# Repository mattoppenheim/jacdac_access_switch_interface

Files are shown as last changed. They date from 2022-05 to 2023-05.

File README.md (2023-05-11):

Accessibility switch interface module for the Microsoft Jacdac project https://microsoft.github.io/jacdac-docs/.

The boards tested as working.

The board has two channels for interfacing accessibility switches or devices that can be controlled by an accessibility switch.

Each channel has a 3.5mm jack socket which can be configured either as an input or an output. This means that a switch can be connected to the board and used to operate Jacdac hardware, or that the module can act as a switch to control external devices or switchable software.

Each channel uses an opto-isolated relay to enable the board to pass enough current so that e.g. switchable toys can be operated.

To use the board as an output to control external hardware or software, use a double ended 3.5mm cable plugged into the 3.5mm socket.

Schematics and PCB layout are made using KiCad Version: 6.99.0-unknown-2887+gf4fa3b02c5+deb11, release build, running on Debian.

The board layout conforms with Ec30Template20x20 80-1.0 drawing.PDF. The Jacdac edge connector conforms with drawing JacdacEdgeConnectorRef 101-1.1 drawing.PDF.

Matthew Oppenheim 2023
matt@mattoppenheim.com

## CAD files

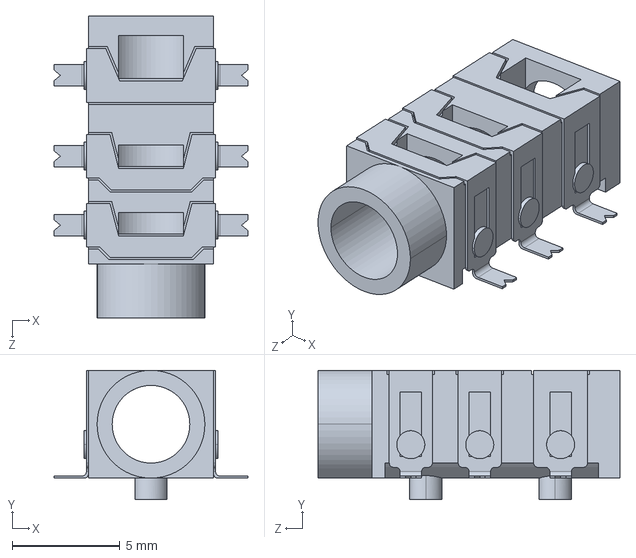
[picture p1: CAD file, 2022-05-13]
3dshapes/JackPJ313D.STEP
9.00 x 6.00 x 14.0 mm

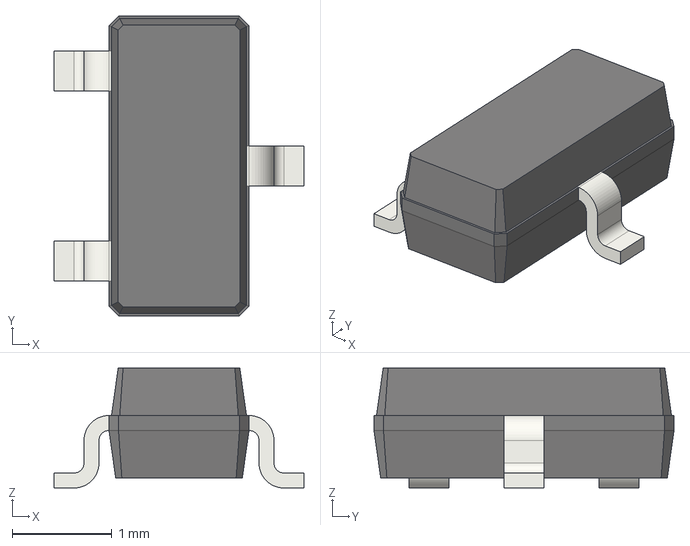
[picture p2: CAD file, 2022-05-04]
3dshapes/SOT-23.step
2.50 x 3.00 x 1.20 mm

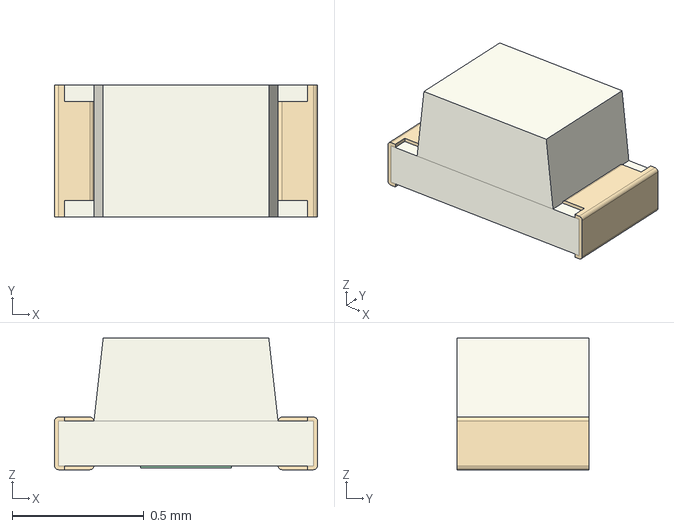
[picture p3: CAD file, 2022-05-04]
3dshapes/LED_0402_1005Metric.step
1.00 x 0.5 x 0.5 mm

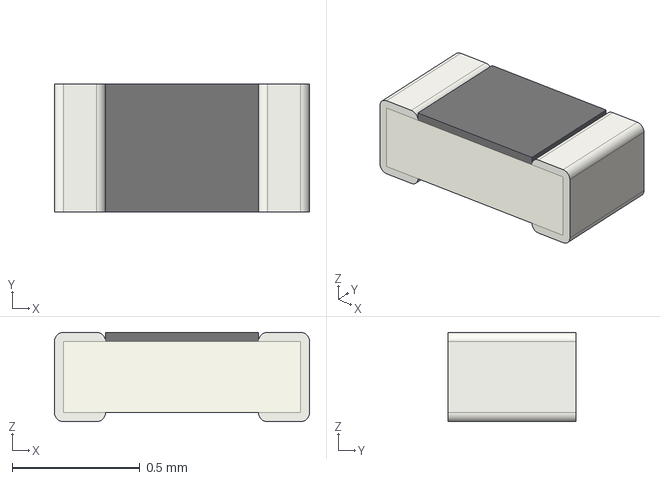
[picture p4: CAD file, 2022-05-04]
3dshapes/R_0402_1005Metric.step
1.00 x 0.5 x 0.35 mm

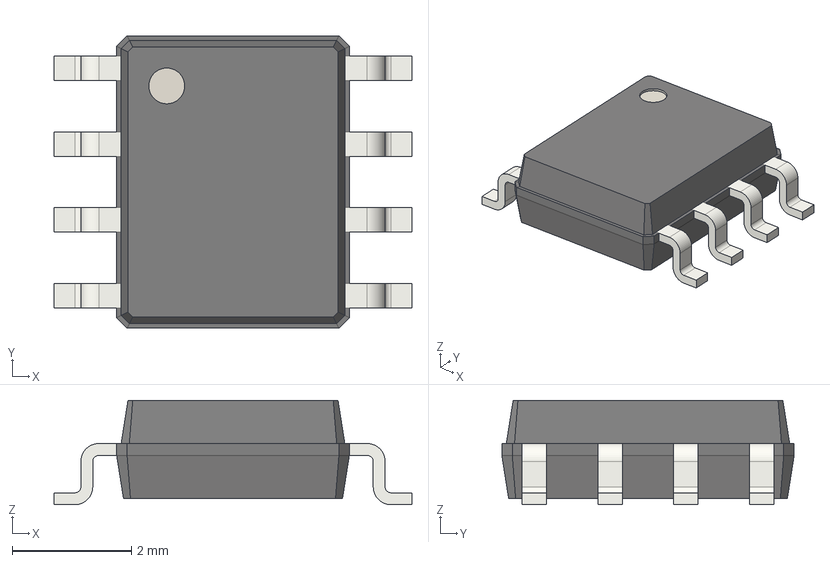
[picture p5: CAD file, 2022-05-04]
3dshapes/SOIC-8_W3.9mm.step
6.00 x 4.90 x 1.75 mm

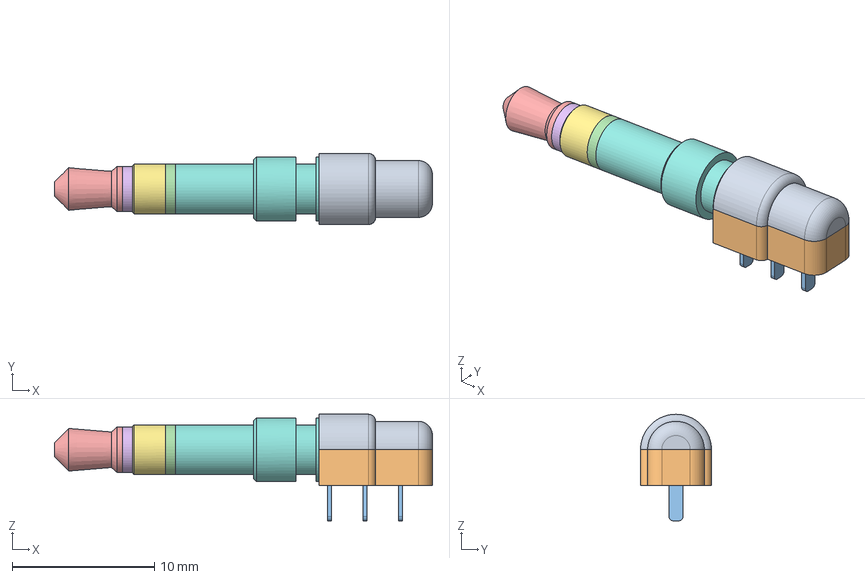
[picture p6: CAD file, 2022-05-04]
3dshapes/Tensility_-_54-00036.step
26.6 x 5.00 x 7.50 mm

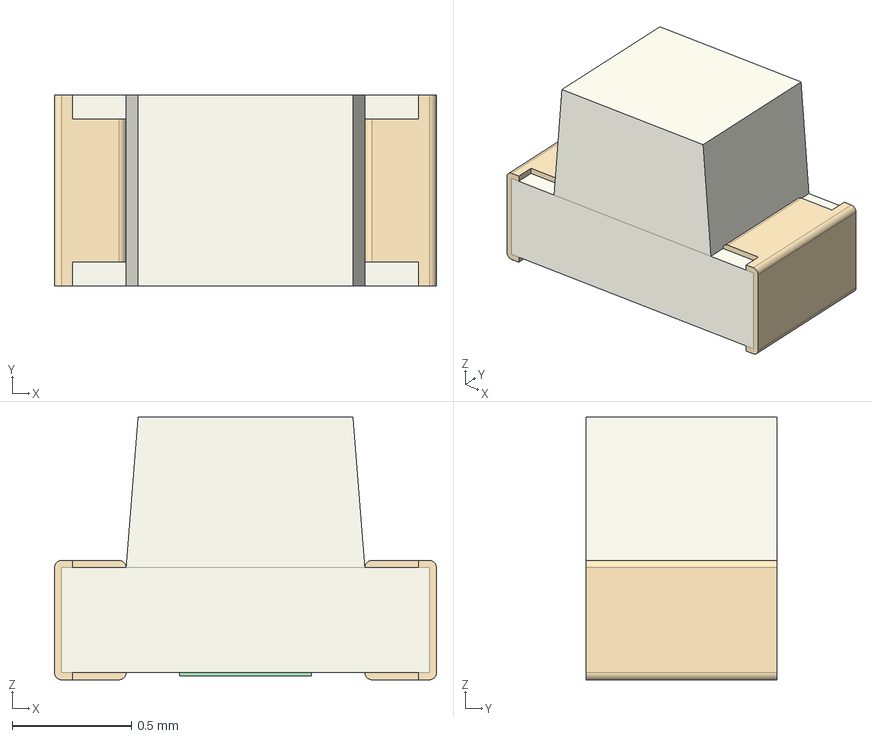
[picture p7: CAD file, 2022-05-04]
3dshapes/LED_0603_1608Metric.step
1.60 x 0.8 x 1.10 mm

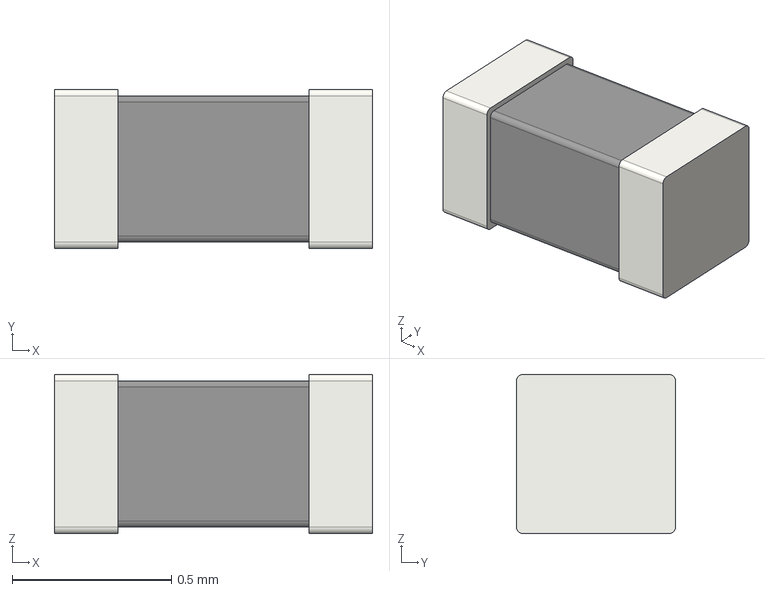
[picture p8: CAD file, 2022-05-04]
3dshapes/L_0402_1005Metric.step
1.00 x 0.5 x 0.5 mm

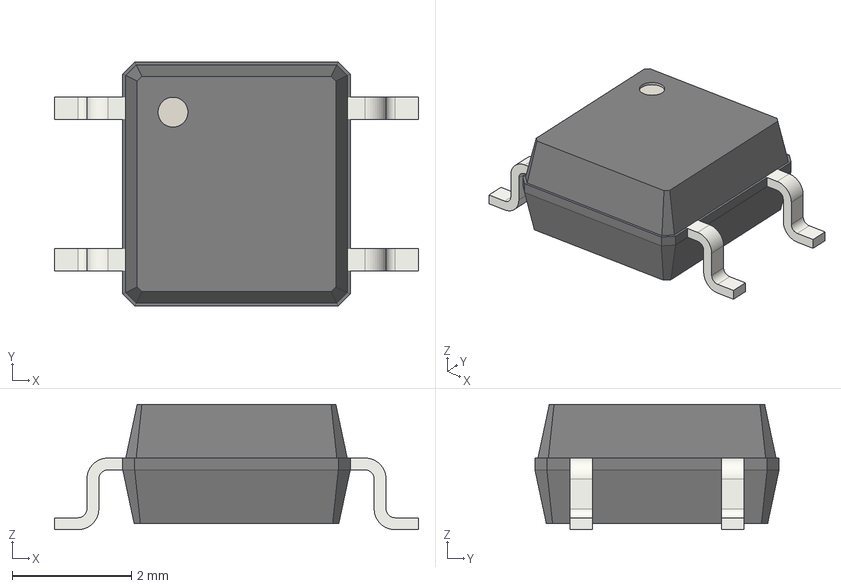
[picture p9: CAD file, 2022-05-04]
3dshapes/SOP-4_3.8x4.1mm_P2.54mm.step
6.10 x 4.09 x 2.10 mm

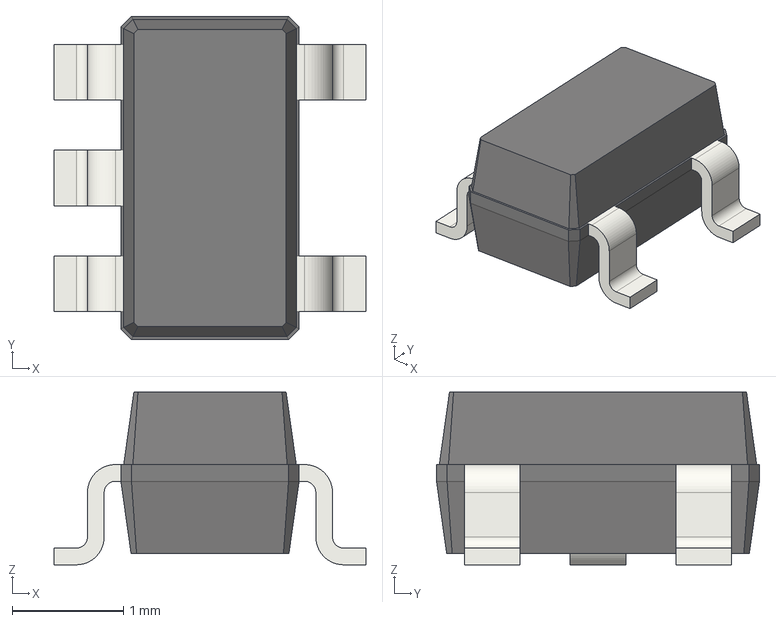
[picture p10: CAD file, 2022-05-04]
3dshapes/SOT-23-5.step
2.80 x 2.90 x 1.55 mm

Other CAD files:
3dshapes/LED_0603_1608Metric_Castellated.step
3dshapes/C_0402_1005Metric.step

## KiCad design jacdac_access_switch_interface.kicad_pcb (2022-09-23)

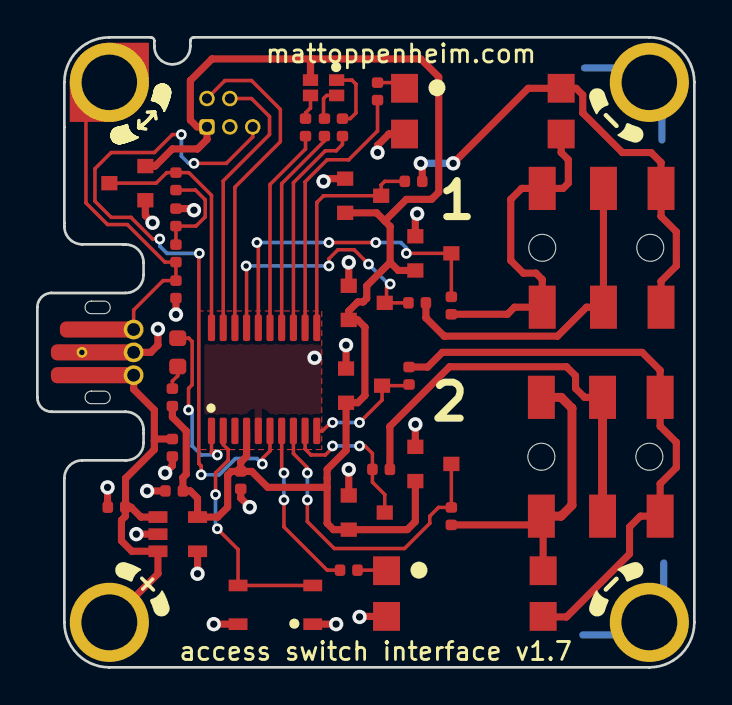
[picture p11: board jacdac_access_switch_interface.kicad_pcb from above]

Board: 2 copper layers, 36.5 x 35.0 mm, 42 parts (0 on the bottom side), 34 nets.

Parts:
C1: 1uF, 10V; C_0402_1005Metric
C2: 1uF; C_0402_1005Metric
C3: 33pF; C_0402_1005Metric
C4: 0.1uF; C_0402_1005Metric
D1: RCLAMP0521P-N; D_0402_1005Metric
D2: RCLAMP0521-P; D_0402_1005Metric
D3, D4, D6, D7, D8, D9, D10: BAT54S; SOT-23
D5: LTST-C19HE1WT; LED_LTST-C19HE1WT
D12: LED_status; LED_0603_1608Metric
FB1: 1kOhm @ 100MHz; L_0402_1005Metric
J1: Conn_Jacdac_CardEdge; JD-PEC-02_Prerouted_recessed
J2: Conn_HackConnect; HackConnect_P1.27mm
J3, J4: jack_3.5_pj313d; jack_3.5_pj313d_smt
MH1: MountingHole_Pad; jacdac_hole_DATA_notched_MH1
MH2: jacdac_hole_GND_MH2
MH3: MountingHole_Pad; jacdac_hole_PWR_MH3
MH4: jacdac_hole_GND_MH4
R1: 220; R_0402_1005Metric
R2, R3: 330; R_0402_1005Metric
R4, R5, R9, R10, R11, R12: 10K; R_0402_1005Metric
R6: 150; R_0402_1005Metric
R7, R8: 33; R_0402_1005Metric
R13: 130; R_0402_1005Metric
SW1: SW_PTS810; SW_SPST_PTS810
U1: NCP114ASN330T1G; SOT-23-5
U2: STM32G030F6P6; TSSOP-20_4.4x6.5mm_P0.65mm
U3, U4: TLP240A; TLP240A_TP1_LF1

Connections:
+3V3: C2.1, C4.1, D3.2 (K), D4.2 (K), D5.4, D6.2 (K), D7.2 (K), D8.2 (K), D9.2 (K), D10.2 (K), J2.1 (Vcc), R13.1, U1.5 (OUT), U2.4 (VDD)
/JD_DATA: D1.1 (A1), FB1.2, J1.1 (JD_DATA), MH1.MH1
/JD_DATA_MCU: D3.3 (common), R1.1, U2.20 (PB3-6/USART1_TX)
/JD_STATUS: D12.1 (K), U2.1 (PB7/PB8)
/RELAY1: R3.2, U2.12 (PA5)
/RELAY2: R2.2, U2.7 (PA0)
/RGB_B: R8.2, U2.15 (PB0/PB1/PB2/PA8)
/RGB_G: R7.2, U2.14 (PA7)
/RGB_R: R6.2, U2.13 (PA6)
/RING1: J3.RING, R9.1
/RING1_P: D7.3 (common), R9.2, U2.17 (PA12[PA10])
/RING2: J4.RING, R12.1
/RING2_P: D10.3 (common), R12.2, U2.9 (PA2)
/SLEEVE1: J3.SLEEVE, R4.1, U4.4
/SLEEVE1_P: D4.3 (common), R4.2, U2.11 (PA4)
/SLEEVE2: J4.SLEEVE, R10.1, U3.3
/SLEEVE2_P: D8.3 (common), R10.2, U2.10 (PA3)
/SWDCLK: J2.4 (SWDCLK), U2.19 (PA15/PA14-BOOT0/SWCLK)
/SWDIO: J2.2 (SWDIO), U2.18 (PA13/SWDIO)
/TIP1: J3.TIP, R5.1, U4.3
/TIP1_P: D6.3 (common), R5.2, U2.16 (PA11[PA9])
/TIP2: J4.TIP, R11.1, U3.4
/TIP2_P: D9.3 (common), R11.2, U2.8 (PA1)
/nFLASH: SW1.2, U2.2 (PB9/PC14)
/nRESET: J2.5 (~RESET), U2.6 (PF2-NRST)
GND: C1.2, C2.2, C3.2, C4.2, D1.2 (A2), D2.2 (A2), D3.1 (A), D4.1 (A), D6.1 (A), D7.1 (A), D8.1 (A), D9.1 (A), D10.1 (A), J1.2 (GND), J2.3 (GND), MH2.MH2, MH4.MH4, SW1.1, U1.2 (GND), U1.4 (NC), U2.5 (VSS), U3.2, U4.2
JD_PWR: C1.1, D2.1 (A1), J1.3 (JD_PWR), MH3.MH3, U1.1 (IN), U1.3 (EN)
unnamed: C3.1, FB1.1, R1.2
unnamed: D5.1, R6.1
unnamed: D5.2, R7.1
unnamed: D5.3, R8.1
unnamed: D12.2 (A), R13.2
unnamed: R2.1, U3.1
unnamed: R3.1, U4.1

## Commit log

2022-05-04 v1.2 added opto-isolater, routing started
    [jacdac_access_switch_interface.kicad_pcb, jacdac_access_switch_interface.kicad_sch, jacdac_access_switch_interface.sch]
2022-05-04 Added 3dshapes and updated PCB
    [C_0402_1005Metric.step, LED_0402_1005Metric.step, LED_0603_1608Metric.step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]
2022-05-11 v1.2 almost routed. Found error in connector placement.
    [jacdac_access_switch_interface.kicad_pcb]
2022-05-11 v1.3 started, board outline complete
    [jacdac_access_switch_interface.kicad_pcb, jacdac_access_switch_interface.kicad_sch, jacdac_access_switch_interface.sch]
2022-05-13 Replaced 3.5mm plug with 2x3.5mm sockets on schematic
    [JackPJ313D.STEP, jacdac_access_switch_interface.kicad_pcb, jacdac_access_switch_interface.kicad_sch]
2022-06-04 Component placement for 30x30 board
    [C_0402_1005Metric.step, JackPJ313D.STEP, LED_0402_1005Metric.step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]
2022-06-04 Laying out 20x30mm board
    [jacdac_access_switch_interface.kicad_pcb]
2022-06-06 Placing components for 30x20mm pcb
    [C_0402_1005Metric.step, JackPJ313D.STEP, LED_0402_1005Metric.step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]
2022-06-07 Components placed, ready for routing
    [jacdac_access_switch_interface.kicad_pcb]
2022-06-07 Setting up v1.5, combined input-output
    [jacdac_access_switch_interface.kicad_pcb, jacdac_access_switch_interface.kicad_sch]
2022-06-08 Moving footprint text from silkscreen to user comments
    [jacdac_access_switch_interface.kicad_pcb]
2022-07-08 Added input protection. Changed MCU to 20 pin STM32G031F6P6
    [jacdac_access_switch_interface.kicad_pcb, jacdac_access_switch_interface.kicad_sch]
2022-07-10 Replaced opto-isoltated relays with discrete FET relays
    [jacdac_access_switch_interface.kicad_pcb, jacdac_access_switch_interface.kicad_sch]
2022-07-20 Changed MCU to STM32G030F6P6, updated input protection resistor to 10K, updated audio symbol
    [jacdac_access_switch_interface.kicad_sch]
2022-07-23 Updated audio socket symbol
    [jacdac_access_switch_interface.kicad_sch]
2022-08-19 Added push button switch to enable flashing & orange status LED
    [jacdac_access_switch_interface.kicad_sch]
2022-08-23 Initial component placement for PCB
    [jacdac_access_switch_interface.kicad_pcb, jacdac_access_switch_interface.kicad_sch]
2022-08-29 Updated footprint identifiers, routing started
    [jacdac_access_switch_interface.kicad_pcb, jacdac_access_switch_interface.kicad_sch]
2022-09-02 Routing in progress
    [jacdac_access_switch_interface.kicad_pcb, jacdac_access_switch_interface.kicad_sch]
2022-09-07 Last commit before re-assigning pins on MCU and spinning MCU
    [jacdac_access_switch_interface.kicad_pcb, jacdac_access_switch_interface.kicad_sch]
2022-09-07 Reassigned pins on MCU and spun MCU, routing ongoing
    [jacdac_access_switch_interface.kicad_pcb, jacdac_access_switch_interface.kicad_sch]
2022-09-14 Routing for PCB v1.7 complete
    [jacdac_access_switch_interface.kicad_pcb]
2022-09-23 v1.7 complete and sent for manufacture
    [jacdac_access_switch_interface.kicad_pcb, jacdac_access_switch_interface.kicad_sch]

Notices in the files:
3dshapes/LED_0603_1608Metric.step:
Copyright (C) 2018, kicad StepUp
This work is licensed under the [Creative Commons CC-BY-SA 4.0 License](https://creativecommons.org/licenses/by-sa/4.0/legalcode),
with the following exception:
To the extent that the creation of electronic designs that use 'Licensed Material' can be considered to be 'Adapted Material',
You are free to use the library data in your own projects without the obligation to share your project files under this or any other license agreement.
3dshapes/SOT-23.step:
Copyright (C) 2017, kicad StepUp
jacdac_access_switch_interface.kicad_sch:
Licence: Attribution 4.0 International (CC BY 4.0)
